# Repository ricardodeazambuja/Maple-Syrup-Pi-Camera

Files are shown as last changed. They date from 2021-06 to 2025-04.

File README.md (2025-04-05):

# Maple Syrup Pi Camera
## Low power('ish) AIoT smart camera (3D printed) based on the Raspberry Pi Zero W and Google Coral EdgeTPU
The Maple Syrup Pi Camera is a low-power, 3D-printed smart camera based on the Raspberry Pi Zero W and Google Coral EdgeTPU. It's designed for on-device AI and computer vision tasks. The project takes advantage of the large Raspberry Pi community and offers both an easy setup via a pre-built SD card image and a more manual installation method. Example applications include object detection like face masks and license plates. While the Raspberry Pi Zero W limits processing speed, it contributes to the camera's low power consumption. Security precautions are advised against direct internet exposure.

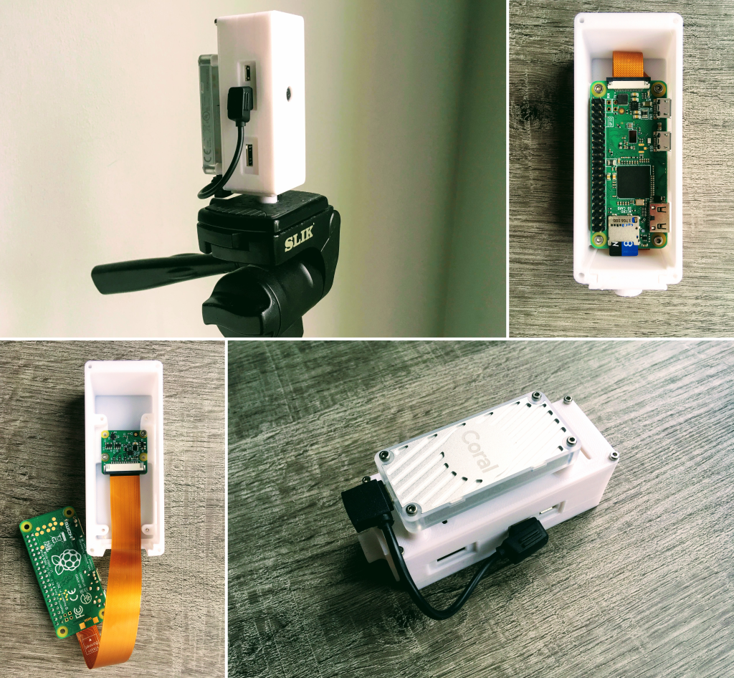
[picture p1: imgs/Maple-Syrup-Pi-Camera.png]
Maple-Syrup-Pi-Camera


People ask me the reason I chose to use the Raspberry Pi Zero for this project considering it's not a powerful single-board computer. I could have tried ready-made smart cameras, but the Raspberry Pi is one of the best selling general purpose computers ever [(beating the Commodore 64, numbers from 4 years ago!)](https://magpi.raspberrypi.org/articles/raspberry-pi-sales), therefore it has a huge community. This makes life much easier when you need to find a driver or how to solve a problem. In addition to that, last year I released my work on a [flexible, collision resilient, quadcopter](https://thecognifly.github.io/) that has as its brain... a Raspberry Pi Zero W! So, I'm quite familiar working with the Zero and I hope the [Raspberry Pi Foundation](https://www.raspberrypi.org/) will soon come up with an upgrade (maybe adding a RP2040 to the RPI Zero PCB?).

## Updates:
The edgetpu runtime version installed in the RPI image is 13, therefore you need to pass `-m 13` to the edgetpu_compiler. The notebooks in this repo are updated, but if you need to compile a different model:
```
edgetpu_compiler -m 13 -s model.tflite
```

### **ATTENTION:**     
The models compiled using the example notebooks that use the Model Maker will ONLY work with this script: [`model_maker_object_detection_from_cam.py`](Examples/model_maker_object_detection_from_cam.py)     
The TL;DR; reason is: the order of the tensors in the output changed, and the pycoral version in the Maple Syrup Pi Camera image has those indices hardcoded. 

## How to build your own

### Hardware
* [Raspberry Pi Zero W](https://www.raspberrypi.org/products/raspberry-pi-zero-w/)
* [Raspberry Pi Camera](https://www.raspberrypi.org/products/camera-module-v2/) ( + [RPI Zero flat cable](https://shop.pimoroni.com/products/camera-cable-raspberry-pi-zero-edition?variant=32092803891283))
* [Coral USB Accelerator](https://coral.ai/products/accelerator)
* [USB-C to micro USB cable](https://www.amazon.co.uk/gp/product/B07WW4J5ZN/) (or [adapter](https://www.amazon.co.uk/ARKTEK-female-Adapter-Samsung-Galaxy-USB-C-Micro/dp/B071W8WQBD/))
* Micro SDCard (if you want to use our image it's recommended 8GB)
* [3D printed parts](3D_files/)

### Software
#### **The easy way**
* Download the image available [here](https://github.com/ricardodeazambuja/Maple-Syrup-Pi-Camera/releases/download/v0.1/maplesyruppicam.img.gz) and flash it to your card using the [Raspberry Pi Imager](https://www.raspberrypi.org/blog/raspberry-pi-imager-imaging-utility/).
* The image available in this repo has lots of interesting stuff pre-installed and its default user is ```pi``` and password ```maplesyrup``` (yup, I love maplesyrup).
* Another interesting thing available is the Jupyter Notebook Server. It helps a lot while testing things. You can launch it by running ```/home/pi/launch_jupyter.sh``` (it's slow at times, but very much usable) and the password is again ```maplesyrup``` (your browser will complain saying it's not a secure connection because the [server is using a self-signed certificate](https://jupyter-notebook.readthedocs.io/en/stable/public_server.html)). 

#### **The hard way (Why can't you go the easy way?!?! LOL)**
* You will, at least, need to install the [libedgetpu and tflite_runtime](https://github.com/ricardodeazambuja/libedgetpu-rpi0/releases/tag/rpi0_tflite_edgetpu). Be aware this tflite_runtime version was compiled for Python 3.7.
* In addition to the software above, you will need to install [Picamera](https://picamera.readthedocs.io/), [Pillow](https://pillow.readthedocs.io/)...

#### **Extra instructions**
* The USB connector is used by the Coral USB Accelerator, therefore it's easier if you use the Maple-Syrup-Pi-Camera [headless](https://www.raspberrypi.org/documentation/configuration/wireless/headless.md). A full example of wifi configuration file is available [here](extras/wpa_supplicant.conf) (you just need to modify it and copy to the boot partition that appears when you connect the SDCard to your computer).
* The image comes with SSH enabled and you can learn more about [how to connect using SSH here](https://www.raspberrypi.org/documentation/remote-access/ssh/README.md).
* If you are a Unix user, you can even [mount the RPI filesystem on your computer and use VSCode remotely](https://ricardodeazambuja.com/linux/2021/05/08/vscode-remotely/).

## Usage examples
* [MultiPose](https://github.com/ricardodeazambuja/MultiPose-EdgeTPU-RPI0)
* [Automatic License Plate Recognition](https://github.com/ricardodeazambuja/ALPR-EdgeTPU-RPI0)
* [Face Mask Detection (Mask, No Mask, Poor Mask)](https://github.com/ricardodeazambuja/MaskDetection-EdgeTPU-RPI0)
* [Examples already installed in the SDCard image](Examples/)
* Train your own Object Detector using [TFLite Model Maker](https://www.tensorflow.org/lite/guide/model_maker):
  * [Annotating your own images using VGG VIA Annotator (**now with Tensorboad!**)](https://github.com/ricardodeazambuja/Maple-Syrup-Pi-Camera/blob/main/Model_Maker_Object_Detection_Tutorial_modified_for_Maple_Syrup_Pi_Camera.ipynb)
  * [Without annotating anything and just using Open Images (**now with Tensorboad!**)](https://github.com/ricardodeazambuja/Maple-Syrup-Pi-Camera/blob/main/Model_Maker_Object_Detection_Tutorial_detect_heads_using_Open_Images_modified_for_Maple_Syrup_Pi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) ([check the labels available](/open_images_labels.md))

## Speed
The RPI Zero W has a USB 2.0 connection with a theoretical 480Mbit/s (50MB/s) speed, but it will never get close to that because the RPI0 has a single core ARMv6 CPU (no free lunch!). Therefore, the Google Coral USB Accelerator is very often limited by the USB bandwidth, or the ability of RPI0 to exchange data with it. This fact plays a role in keeping the average power consumption low, though. Models that need post-processing or use a custom OP (the EdgeTPU compiler runs these ops in the host) will also suffer from the small USB bandwidth and the weak ARMv6 single core.

## Power consumption:
The RPI Zero W has no protection circuit on its 5V input, therefore it connects the USB power directly to the power supply. That means the Coral USB Accelerator will be directly connected to the power supply allowing it to drain as much current as the power supply and impedance of microUSB + PCB traces allow it. According to the [Google Coral USB Accelerator Datasheet](https://coral.ai/static/files/Coral-USB-Accelerator-datasheet.pdf), the accelerator alone could draw up to 900mA (peak). The RPI Zero W has a [typical power consumption of 150mA](https://www.raspberrypi.org/documentation/hardware/raspberrypi/power/README.md). In my experiments, the Maple-Syrup-Pi-Camera consumes around 160mA at 5V when idle (800mW).
* Since the speed is limited by other factors than the Coral USB accelerator, it's possible to save energy by using [the throttled version of the libedgetpu](https://github.com/ricardodeazambuja/libedgetpu-rpi0/releases/tag/rpi0_tflite_edgetpu).

### Examples of power consumption:  
Using a hobby-grade USB power meter (and a power bank that states it can deliver up to 2A at 5V):
* [MultiPose](https://github.com/ricardodeazambuja/MultiPose-EdgeTPU-RPI0) shows peaks of 350mA at 5V (1.75W)
* [Automatic License Plate Recognition](https://github.com/ricardodeazambuja/ALPR-EdgeTPU-RPI0) shows peaks of 400mA at 5V (2W)
* [Face Mask Detection (Mask, No Mask, Poor Mask)](https://github.com/ricardodeazambuja/MaskDetection-EdgeTPU-RPI0) shows peaks of 420mA at 5V (2.1W)  

The power consumption is kept low, compared to other products using the EdgeTPU, mainly because the RPI Zero is very low power and the Coral USB accelerator usually sits idle awaiting for data.

## Acknowledgments:
* 3D parts adapted from https://www.thingiverse.com/thing:2254307
* [Instructions on how to create RPI images using docker](https://ricardodeazambuja.com/rpi/2020/12/29/rpi2docker/)
* Some models and project examples are from https://coral.ai/examples/ and https://github.com/google-coral/pycoral
* SDCard image adapted from the collision resilient quadcopter [CogniFly](https://thecognifly.github.io/).
* Life is just much easier thanks to [Netron](https://netron.app/)

## Disclaimer
* Don't expose it directly to the world-WILD-web (aka "[the internet](https://en.wikipedia.org/wiki/Internet)") without a good [firewall](https://en.wikipedia.org/wiki/Firewall_(computing)). Some suggestions:
   * [Securing your Raspberry Pi](https://www.raspberrypi.org/documentation/configuration/security.md)
   * [IoT Security Foundation](https://www.iotsecurityfoundation.org/best-practice-guidelines/)
* Use it at your own risk and, please, [don't be evil](https://www.youtube.com/watch?v=b23wrRfy7SM) ;)

## Other projects you may like to check:
* [RPI0_GPU_FFT](https://github.com/ricardodeazambuja/RPI0_GPU_FFT): Experiments using the RPI Zero GPU for FFT/IFFT 1D/2D.
* [colab_utils](https://github.com/ricardodeazambuja/colab_utils/): Some useful (or not so much) Python stuff for Google Colab notebooks.
* [ExecThatCell](https://github.com/ricardodeazambuja/ExecThatCell): (Re)Execute a Jupyter (colab) notebook cell programmatically by searching for its label.
* [The CogniFly Project](https://github.com/thecognifly): Open-source autonomous flying robots robust to collisions and smart enough to do something interesting!
* [Bee](https://github.com/ricardodeazambuja/Bee): The Bee simulator is an open source Spiking Neural Network (SNN) simulator, freely available, specialised in Liquid State Machine (LSM) systems with its core functions fully implemented in C.

---

### This project has received funding from the European Union’s Horizon 2020 research and innovation programme under the Marie Skłodowska-Curie grant agreement No 801215 and the University of Edinburgh Data-Driven Innovation programme, part of the Edinburgh and South East Scotland City Region Deal
https://ddi.ac.uk/case-studies/smart-tourism-in-the-age-of-the-general-data-protection-regulation-capturing-rich-visitor-flow-data-without-risking-privacy-invasion/

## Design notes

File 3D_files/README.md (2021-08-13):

# 3D Files
<p align="center">

</p>

STL files for 3D printing. All files are easy to print in any hobby grade printer. Gcode and 3mf files were added to help in the selection of settings.

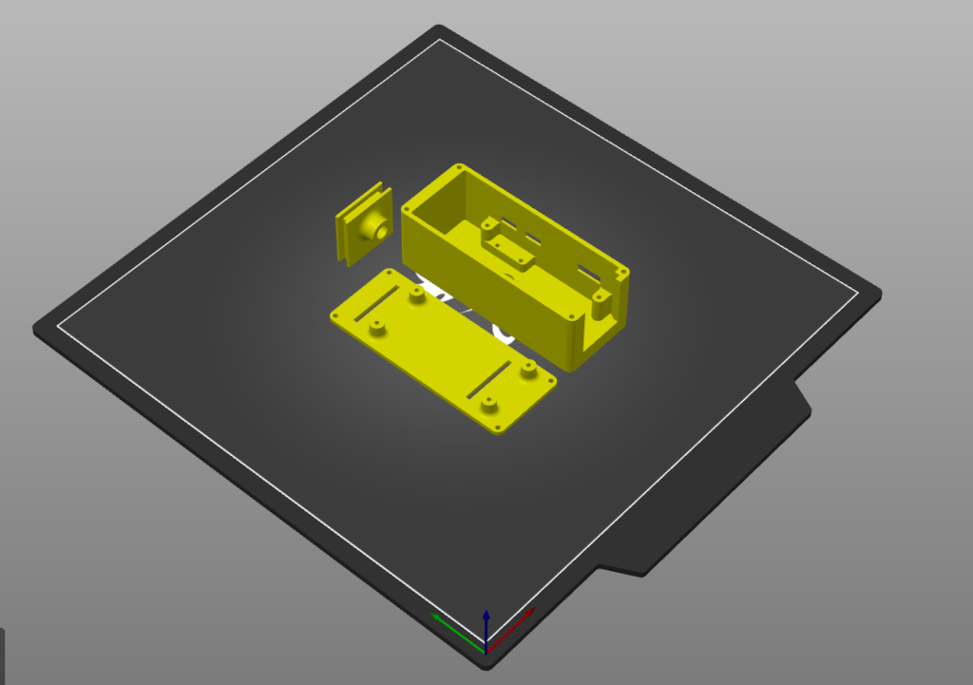
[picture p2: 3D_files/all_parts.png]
All Parts


The bottom part is very much a snug fit to keep the SDCard from getting loose, so be careful not to damage the SDCard / connector when assembling it (the [sdcard_lid_tripod_connector](sdcard_lid_tripod_connector.stl) may need some sanding to reduce thickness depending on your printing quality).

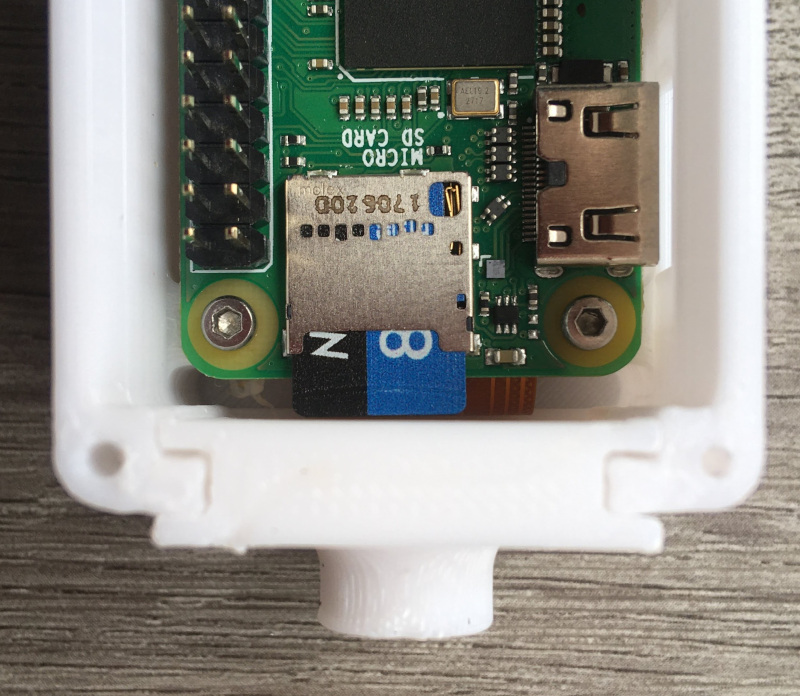
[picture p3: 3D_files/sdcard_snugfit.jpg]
SDCard snug fit


### In addition to the 3D parts, you will need some screws:
* M2x6 (4x rpi0, 4x lid).
* M2x5 or M2x4 (4x camera).
* M2x12 (4x Coral USB).

## Acknowledgments:
* 3D case based on https://www.thingiverse.com/thing:2254307

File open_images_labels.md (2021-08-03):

# [Open Images](https://storage.googleapis.com/openimages/web/visualizer/index.html?set=train&type=detection&c=%2Fm%2F03bbps) 600 labels (object detection / bounding box) in alphabetical order

## Training set
| Labels 0 to 59 [totals] | Labels 60 to 119 [totals] | Labels 180 to 239 [totals] | Labels 300 to 359 [totals] | Labels 360 to 419 [totals] | Labels 420 to 479 [totals] | Labels 480 to 539 [totals] | Labels 540 to 599 [totals] |
|---|---|---|---|---|---|---|---|
| Accordion [955] | Bowl [4507] | Envelope [177] | Ladybug [734] | Oven [637] | Remote control [236] | Spatula [64] | Tomato [6254] |
| Adhesive tape [255] | Bowling equipment [3846] | Eraser [53] | Lamp [3663] | Owl [1663] | Reptile [578] | Spice rack [131] | Tool [2075] |
| Aircraft [1898] | Box [5364] | Face powder [80] | Land vehicle [81108] | Oyster [1038] | Rhinoceros [724] | Spider [2033] | Toothbrush [219] |
| Airplane [21285] | Boy [87555] | Facial tissue holder [20] | Lantern [5429] | Paddle [6951] | Rifle [2540] | Spoon [1709] | Torch [20] |
| Alarm clock [169] | Brassiere [1694] | Falcon [1717] | Laptop [9327] | Palm tree [42026] | Ring binder [84] | Sports equipment [44900] | Towel [338] |
| Alpaca [829] | Bread [3846] | Fashion accessory [91024] | Lavender (Plant) [6472] | Pancake [775] | Rocket [918] | Sports uniform [19396] | Tower [67945] |
| Ambulance [447] | Briefcase [162] | Fast food [24991] | Lemon [1756] | Panda [882] | Roller skates [5476] | Squash (Plant) [375] | Toy [70963] |
| Animal [17442] | Broccoli [1128] | Fax [28] | Leopard [811] | Paper cutter [4] | Rose [12053] | Squid [221] | Traffic light [7426] |
| Ant [925] | Bronze sculpture [2748] | Fedora [3660] | Light bulb [1816] | Paper towel [210] | Rugby ball [294] | Squirrel [1940] | Traffic sign [6112] |
| Antelope [1568] | Brown bear [647] | Filing cabinet [374] | Light switch [97] | Parachute [2672] | Ruler [253] | Stairs [5981] | Train [13050] |
| Apple [3898] | Building [178634] | Fire hydrant [432] | Lighthouse [1518] | Parking meter [209] | Salad [3088] | Stapler [59] | Training bench [194] |
| Armadillo [56] | Bull [1736] | Fireplace [711] | Lily [2252] | Parrot [2388] | Salt and pepper shakers [180] | Starfish [639] | Treadmill [247] |
| Artichoke [376] | Burrito [262] | Fish [23195] | Limousine [366] | Pasta [769] | Sandal [2938] | Stationary bicycle [338] | Tree [1051344] |
| Auto part [13586] | Bus [11927] | Flag [29246] | Lion [1653] | Pastry [5852] | Sandwich [1157] | Stethoscope [78] | Tree house [110] |
| Axe [148] | Bust [1060] | Flashlight [88] | Lipstick [1343] | Peach [756] | Saucer [2819] | Stool [1254] | Tripod [1446] |
| Backpack [1216] | Butterfly [10127] | Flower [345296] | Lizard [2120] | Pear [923] | Saxophone [1208] | Stop sign [394] | Trombone [953] |
| Bagel [640] | Cabbage [435] | Flowerpot [22760] | Lobster [597] | Pen [1705] | Scale [139] | Strawberry [7944] | Trousers [8481] |
| Baked goods [23010] | Cabinetry [9191] | Flute [362] | Loveseat [631] | Pencil case [132] | Scarf [2303] | Street light [44697] | Truck [12135] |
| Balance beam [326] | Cake [5784] | Flying disc [249] | Luggage and bags [2220] | Pencil sharpener [21] | Scissors [399] | Stretcher [174] | Trumpet [1546] |
| Ball [6845] | Cake stand [337] | Food [88422] | Lynx [237] | Penguin [4197] | Scoreboard [517] | Studio couch [1889] | Turkey [734] |
| Balloon [13505] | Calculator [210] | Food processor [192] | Magpie [145] | Perfume [363] | Scorpion [204] | Submarine [81] | Turtle [205] |
| Banana [1612] | Camel [1340] | Football [5097] | Mammal [156154] | Person [1034721] | Screwdriver [85] | Submarine sandwich [273] | Umbrella [7204] |
| Band-aid [36] | Camera [6404] | Football helmet [11705] | Man [1418594] | Personal care [409] | Sculpture [34533] | Suit [110848] | Unicycle [194] |
| Banjo [264] | Can opener [7] | Footwear [744474] | Mango [429] | Personal flotation device [3678] | Sea lion [1823] | Suitcase [630] | Van [7720] |
| Barge [983] | Canary [387] | Fork [1687] | Maple [4923] | Piano [1374] | Sea turtle [1132] | Sun hat [6979] | Vase [2468] |
| Barrel [2086] | Candle [5886] | Fountain [3691] | Maracas [10] | Picnic basket [425] | Seafood [3063] | Sunglasses [23996] | Vegetable [18621] |
| Baseball bat [1228] | Candy [2261] | Fox [565] | Marine invertebrates [9112] | Picture frame [11957] | Seahorse [314] | Surfboard [2594] | Vehicle [50959] |
| Baseball glove [2529] | Cannon [1087] | French fries [2114] | Marine mammal [1746] | Pig [1613] | Seat belt [461] | Sushi [2088] | Vehicle registration plate [7852] |
| Bat (Animal) [655] | Canoe [4543] | French horn [1239] | Measuring cup [74] | Pillow [3508] | Segway [565] | Swan [4523] | Violin [2828] |
| Bathroom accessory [2678] | Cantaloupe [166] | Frog [1608] | Mechanical fan [681] | Pineapple [660] | Serving tray [118] | Swim cap [615] | Volleyball (Ball) [661] |
| Bathroom cabinet [358] | Car [248075] | Fruit [26236] | Medical equipment [2060] | Pitcher (Container) [347] | Sewing machine [453] | Swimming pool [3881] | Waffle [710] |
| Bathtub [545] | Carnivore [3501] | Frying pan [377] | Microphone [27272] | Pizza [2008] | Shark [625] | Swimwear [10079] | Waffle iron [31] |
| Beaker [168] | Carrot [1456] | Furniture [38527] | Microwave oven [485] | Pizza cutter [20] | Sheep [3438] | Sword [567] | Wall clock [1067] |
| Bear [427] | Cart [2755] | Garden Asparagus [387] | Milk [214] | Plant [267913] | Shelf [22899] | Syringe [127] | Wardrobe [238] |
| Bed [3563] | Cassette deck [74] | Gas stove [526] | Miniskirt [954] | Plastic bag [986] | Shellfish [1287] | Table [85691] | Washing machine [655] |
| Bee [11401] | Castle [4310] | Giraffe [1431] | Mirror [1572] | Plate [5416] | Shirt [7465] | Table tennis racket [849] | Waste container [1807] |
| Beehive [511] | Cat [15183] | Girl [197155] | Missile [603] | Platter [3462] | Shorts [16981] | Tablet computer [975] | Watch [1903] |
| Beer [9565] | Cat furniture [208] | Glasses [57946] | Mixer [216] | Plumbing fixture [481] | Shotgun [580] | Tableware [41086] | Watercraft [5202] |
| Beetle [3523] | Caterpillar [884] | Glove [1198] | Mixing bowl [1005] | Polar bear [664] | Shower [235] | Taco [677] | Watermelon [844] |
| Bell pepper [802] | Cattle [11603] | Goat [2075] | Mobile phone [6365] | Pomegranate [677] | Shrimp [1856] | Tank [1716] | Weapon [2960] |
| Belt [422] | Ceiling fan [478] | Goggles [9636] | Monkey [3026] | Popcorn [362] | Sink [1648] | Tap [1695] | Whale [1014] |
| Bench [7229] | Cello [2004] | Goldfish [2204] | Moths and butterflies [1857] | Porch [3854] | Skateboard [1810] | Tart [973] | Wheel [340639] |
| Bicycle [40161] | Centipede [280] | Golf ball [434] | Motorcycle [13382] | Porcupine [229] | Ski [3505] | Taxi [4199] | Wheelchair [1464] |
| Bicycle helmet [15952] | Chainsaw [130] | Golf cart [595] | Mouse [857] | Poster [23566] | Skirt [1259] | Tea [1342] | Whisk [180] |
| Bicycle wheel [59521] | Chair [132483] | Gondola [1868] | Muffin [4608] | Potato [599] | Skull [2661] | Teapot [632] | Whiteboard [1003] |
| Bidet [440] | Cheese [1560] | Goose [8436] | Mug [2272] | Power plugs and sockets [290] | Skunk [56] | Teddy bear [1587] | Willow [735] |
| Billboard [9823] | Cheetah [715] | Grape [2787] | Mule [1117] | Pressure cooker [14] | Skyscraper [81261] | Telephone [274] | Window [503467] |
| Billiard table [912] | Chest of drawers [1526] | Grapefruit [1283] | Mushroom [4497] | Pretzel [294] | Slow cooker [125] | Television [3789] | Window blind [570] |
| Binoculars [123] | Chicken [3059] | Grinder [14] | Musical instrument [16503] | Printer [263] | Snack [37374] | Tennis ball [502] | Wine [15400] |
| Bird [47921] | Chime [41] | Guacamole [224] | Musical keyboard [1771] | Pumpkin [6150] | Snail [943] | Tennis racket [985] | Wine glass [12934] |
| Blender [235] | Chisel [33] | Guitar [25896] | Nail (Construction) [491] | Punching bag [336] | Snake [1378] | Tent [6907] | Wine rack [254] |
| Blue jay [259] | Chopsticks [617] | Hair dryer [27] | Necklace [2735] | Rabbit [1641] | Snowboard [944] | Tiara [411] | Winter melon [43] |
| Boat [79113] | Christmas tree [4243] | Hair spray [10] | Nightstand [1125] | Raccoon [381] | Snowman [770] | Tick [143] | Wok [730] |
| Bomb [8] | Clock [1222] | Hamburger [1486] | Oboe [162] | Racket [281] | Snowmobile [366] | Tie [10545] | Woman [767337] |
| Book [41280] | Closet [661] | Hammer [139] | Office building [4986] | Radish [688] | Snowplow [300] | Tiger [1260] | Wood-burning stove [300] |
| Bookcase [5307] | Clothing [1438128] | Hamster [546] | Office supplies [6198] | Ratchet (Device) [327] | Soap dispenser [78] | Tin can [2988] | Woodpecker [515] |
| Boot [3132] | Coat [6523] | Hand dryer [70] | Orange [6195] | Raven [567] | Sock [1425] | Tire [122615] | Worm [270] |
| Bottle [40188] | Cocktail [4458] | Handbag [2495] | Organ (Musical Instrument) [398] | Rays and skates [485] | Sofa bed [1501] | Toaster [73] | Wrench [204] |
| Bottle opener [21] | Cocktail shaker [27] | Handgun [727] | Ostrich [640] | Red panda [423] | Sombrero [651] | Toilet [1099] | Zebra [1120] |
| Bow and arrow [594] | Coconut [874] | Harbor seal [2084] | Otter [752] | Refrigerator [592] | Sparrow [1651] | Toilet paper [377] | Zucchini [1098] |

### Train your own model by following the steps on [this notebook](https://github.com/ricardodeazambuja/Maple-Syrup-Pi-Camera/blob/main/Model_Maker_Object_Detection_Tutorial_detect_heads_using_Open_Images_modified_for_Maple_Syrup_Pi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).

### As some classes don't have a lot of samples available (e.g. "Cocktail shaker" has only 27, not sure why you would want a object detector trained on this, but I'm not here to judge :D), you may need to augment your dataset. One easy option is to use [colab_utils](https://github.com/ricardodeazambuja/colab_utils) `augment_dataset`. You can find a usage example on [this notebook](https://github.com/ricardodeazambuja/Maple-Syrup-Pi-Camera/blob/main/Model_Maker_Object_Detection_Tutorial_modified_for_Maple_Syrup_Pi_Camera.ipynb).

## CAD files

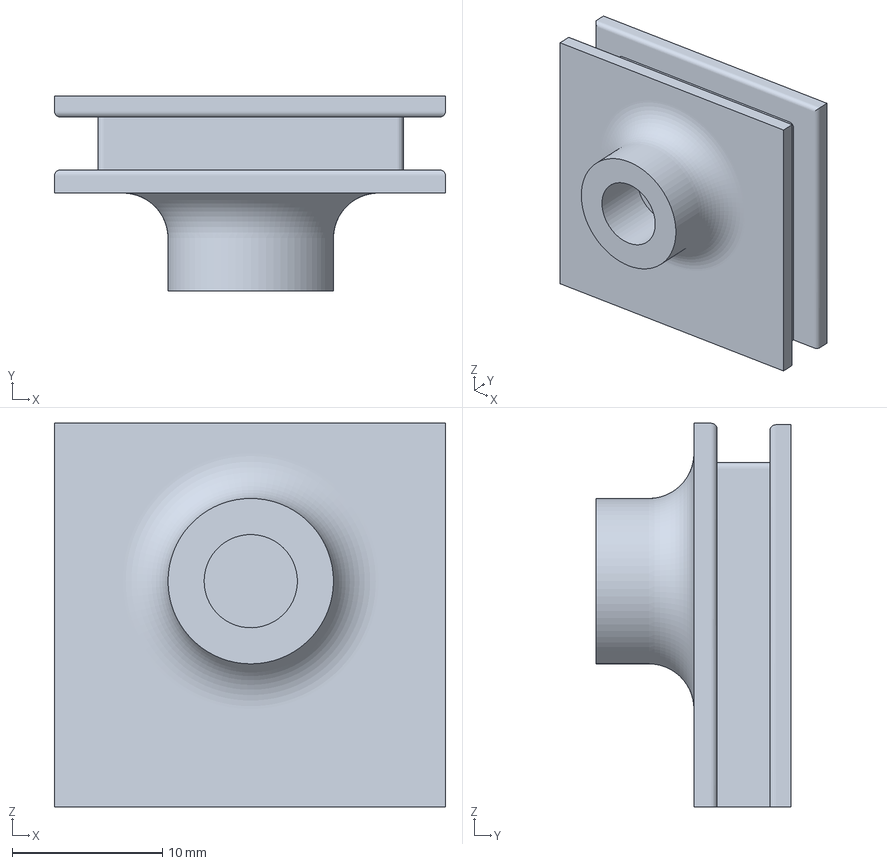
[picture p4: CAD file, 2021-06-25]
3D_files/sdcard_lid_tripod_connector.3mf
26.0 x 13.0 x 25.5 mm

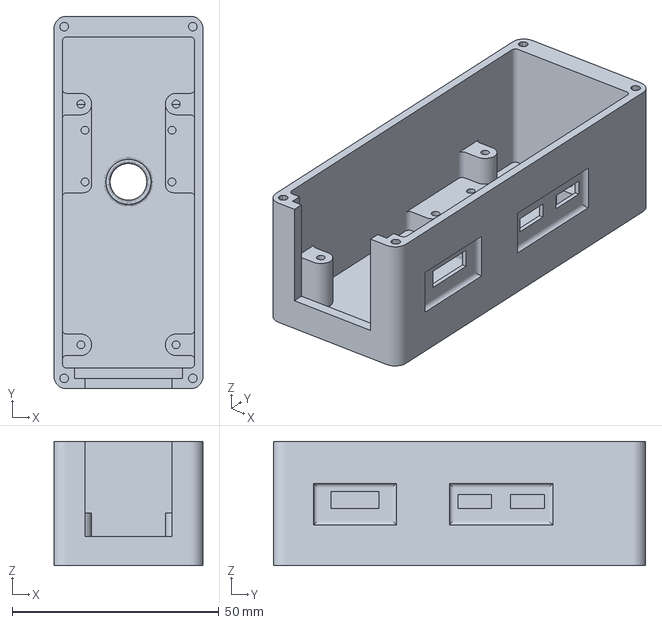
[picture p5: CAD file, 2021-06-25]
3D_files/case.3mf
36.0 x 90.0 x 30.0 mm

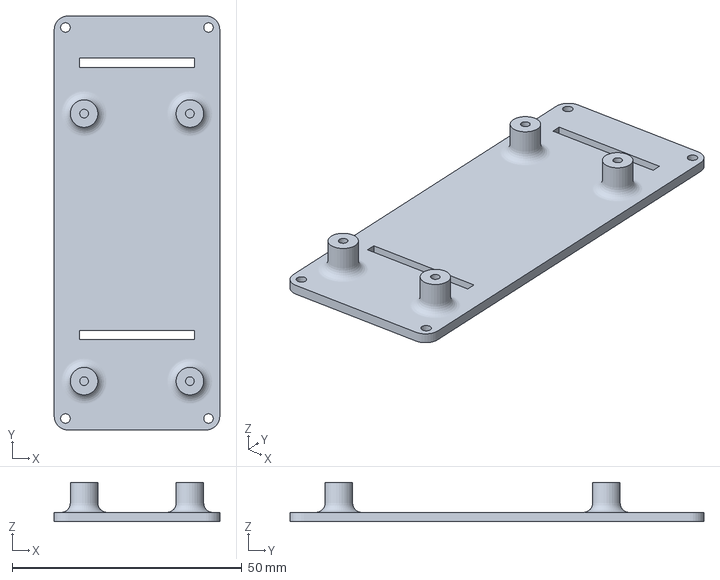
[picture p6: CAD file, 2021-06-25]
3D_files/lid.3mf
36.0 x 90.0 x 8.50 mm

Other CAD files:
3D_files/case.stl
3D_files/lid.stl
3D_files/sdcard_lid_tripod_connector.stl

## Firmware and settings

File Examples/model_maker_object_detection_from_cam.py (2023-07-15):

import io
import time
import argparse
import numpy as np
from picamera import PiCamera


from PIL import Image
from PIL import ImageDraw

from pycoral.adapters import common
from pycoral.adapters import detect
from pycoral.utils.dataset import read_label_file
from pycoral.utils.edgetpu import make_interpreter


colors = {0: (128, 255, 102), 1: (102, 255, 255)}

    
def main():
    parser = argparse.ArgumentParser(
        formatter_class=argparse.ArgumentDefaultsHelpFormatter)
    parser.add_argument('-m', '--model', required=True,
                        help='File path of .tflite file.')
    parser.add_argument('-l', '--labels',
                        help='File path of labels file.')
    parser.add_argument('-t', '--threshold', type=float, default=0.0,
                        help='Classification score threshold')
    parser.add_argument('--debug', dest='debug', action='store_true',
                        help='Saves the last image to last_image_obj_detec_from_cam.jpg')
    args = parser.parse_args()

    print(f"Initializing EdgeTPU... {args.model} and {args.labels}")
    labels = read_label_file(args.labels) if args.labels else {}
    interpreter = make_interpreter(*args.model.split('@'))
    interpreter.allocate_tensors()
    size = common.input_size(interpreter)
    interpreter.invoke()  # warmup
    input_details = interpreter.get_input_details()
    output_details = interpreter.get_output_details()
    print(f"Model input details:\n{input_details}")
    print(f"Model output details:\n{output_details}")

    
    def process_img(image):
        interpreter.set_tensor(input_details[0]['index'], image)
        interpreter.invoke()
        scores = interpreter.get_tensor(output_details[0]['index'])[0]
        boxes = interpreter.get_tensor(output_details[1]['index'])[0]
        num_detections = interpreter.get_tensor(output_details[2]['index'])[0]
        classes = interpreter.get_tensor(output_details[3]['index'])[0]

        return boxes, classes, scores, num_detections

    print("Initializing picamera...")
    # See https://picamera.readthedocs.io/en/release-1.13/api_camera.html
    # for details about the parameters:

    print("Starting...")
    # Start the video process
    stream = io.BytesIO()    
    time.sleep(2)
    try:
        with PiCamera() as camera:
            camera.resolution = (320, 320)
            camera.framerate = 60
            # camera.contrast = contrast
            camera.video_stabilization = True
            camera.video_denoise = True
            #camera.rotation = 180

            start = time.perf_counter()
            for _ in camera.capture_continuous(stream, format='rgb'):
                print(f'Running at {(1/(time.perf_counter() - start)):.2f} fps')
                start = time.perf_counter()
                stream.truncate()
                stream.seek(0)
                image = Image.fromarray(np.frombuffer(stream.getvalue(), dtype=np.uint8).reshape((320,320,3))).convert('RGB').resize(size, Image.ANTIALIAS)
                if image:
                    np_image = np.asarray(image)
                    input_tensor = np.expand_dims(np_image, axis=0)
                    boxes, classes, scores, num_detections = process_img(input_tensor)
                    for i in range(int(num_detections)):
                        if scores[i] >= args.threshold:
                            ymin = int(max(1, (boxes[i][0] * size[1])))
                            xmin = int(max(1, (boxes[i][1] * size[0])))
                            ymax = int(min(size[1], (boxes[i][2] * size[1])))
                            xmax = int(min(size[0], (boxes[i][3] * size[0])))
                    # for obji,obj in enumerate(objs):
                            print(f"Obj #{i} (Confidence {int(100*scores[i])}%): {labels.get(int(classes[i]))} - {(xmin,ymin),(xmax,ymax)}\n")
    except KeyboardInterrupt:
        pass
    finally:
        if args.debug and image:
            dimage = ImageDraw.Draw(image)
            if len(boxes):
                for i in range(int(num_detections)):
                    if scores[i] >= args.threshold:
                        ymin = int(max(1, (boxes[i][0] * size[1])))
                        xmin = int(max(1, (boxes[i][1] * size[0])))
                        ymax = int(min(size[1], (boxes[i][2] * size[1])))
                        xmax = int(min(size[0], (boxes[i][3] * size[0])))
                        dimage.rectangle((xmin, ymin, xmax, ymax), width=7,
                                        outline=colors[int(classes[i])])
                        dimage.rectangle((xmin, ymin, xmax, ymin-10),
                                        fill=colors[int(classes[i])])
                        try:
                            label = labels[int(classes[i])]
                        except KeyError:
                            label = "None"
                        text = label + ' ' + str(scores[i]*100) + '%'
                        dimage.text((xmin+2, ymin-10), text, fill=(0, 0, 0), width=5)

            image.save("last_image_obj_detec_from_cam.jpg")
            print("last_image_obj_detec_from_cam.jpg saved!")
        
        print("Done!")

if __name__ == '__main__':
    main()

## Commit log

2021-08-13 Added gif of the printing process
2023-07-15 Fixed problems with models generated with Model Maker
    [model_maker_object_detection_from_cam.py]
